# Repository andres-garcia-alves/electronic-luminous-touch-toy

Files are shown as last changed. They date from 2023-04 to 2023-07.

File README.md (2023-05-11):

# Luminous Touch Toy

Luminous Touch Toy made with NE555 IC and a piezo-electric sensor, with auto-off functionality.

&nbsp;

This project use the following electronic components:
- 1 x Integrated circuit NE555
- 1 x Piezo-electric sensor
- 4 x Multi-color LEDs
- 4 x 330 ohm resistors
- 1 x 10k ohm resistors
- 1 x 100k ohm resistor
- 1 x Transistor BC547 NPN
- 1 x Electrolitic capacitor 100uF 10v
- 1 x Switch-button
- 4 x Bateries 1.5v
- Some Empty Pen Tubes

The circuit:
- When pressing the toy surface it moves the empty pen tubes, making some presure on the piezo-electric.
- The piezo-electric generates some voltage on presure, activating the electronic circuit.
- The NE555 IC handles the 12 seconds enabled delay.

Notes:
- KiCad 6.0 schematic & PCB blueprints are also included.

&nbsp;

### Screenshots

| Diagram - Schematics | Diagram - PCB |
|---|---|
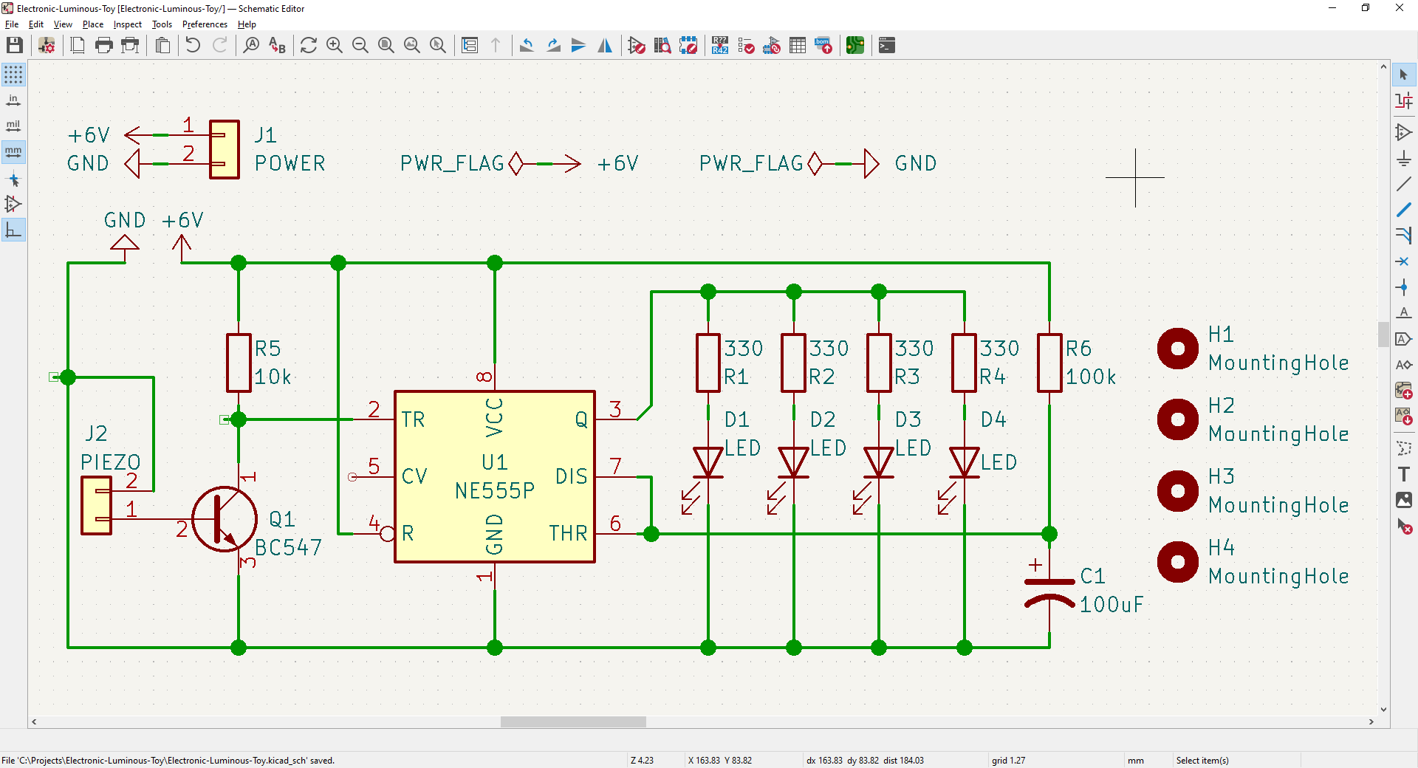
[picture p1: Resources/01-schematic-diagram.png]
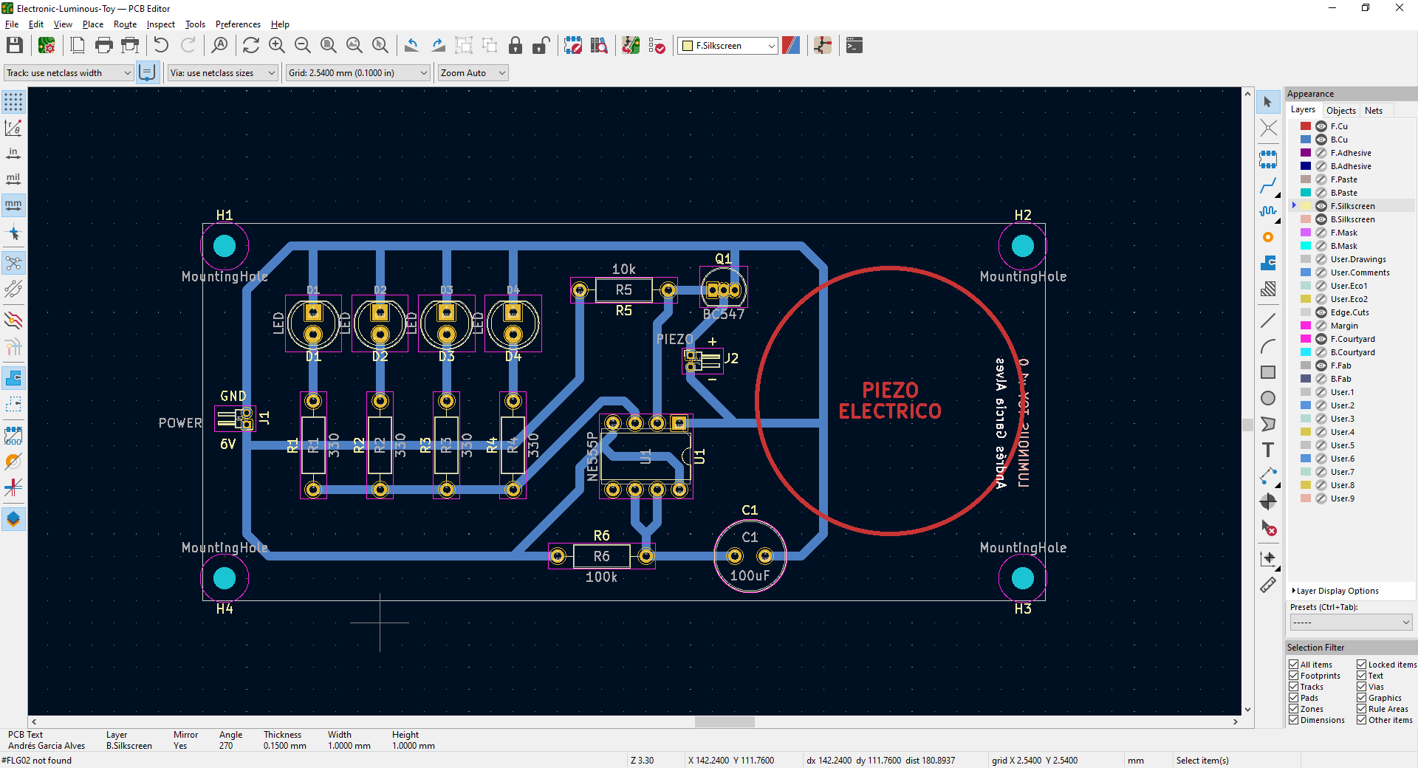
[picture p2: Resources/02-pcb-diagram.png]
|  |  |

| Diagram - PCB Render | Diagram - PCB Render |
|---|---|
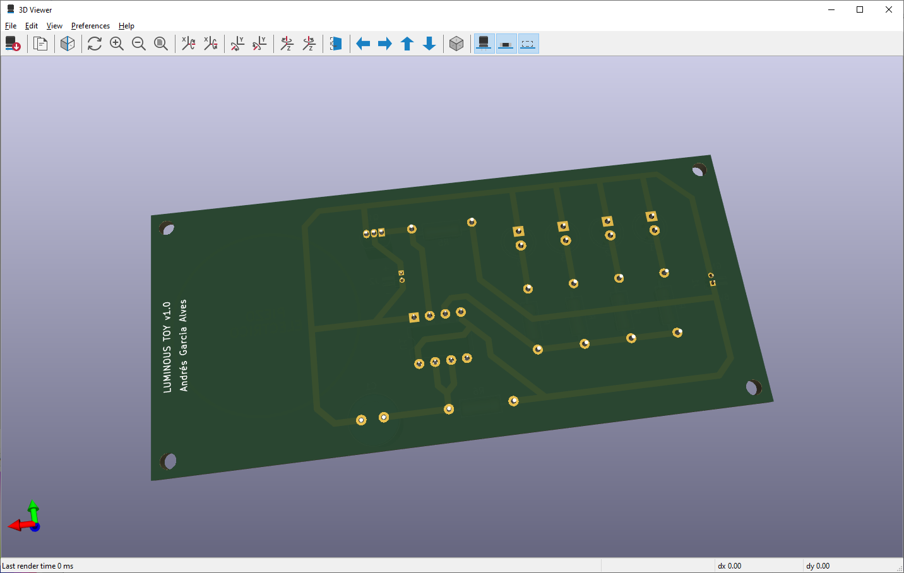
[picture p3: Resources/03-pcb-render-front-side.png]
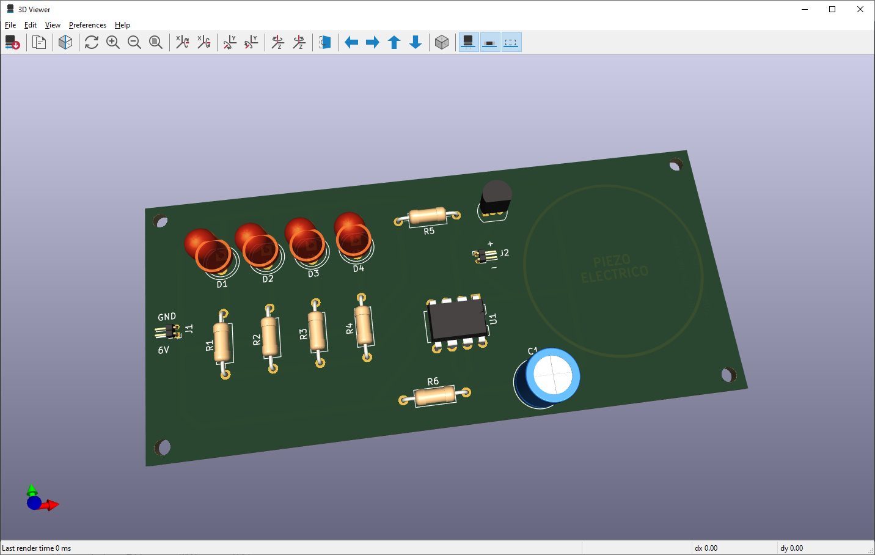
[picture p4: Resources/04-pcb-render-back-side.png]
|  |  |

| Prototype | PCB Manufacturing |
|---|---|
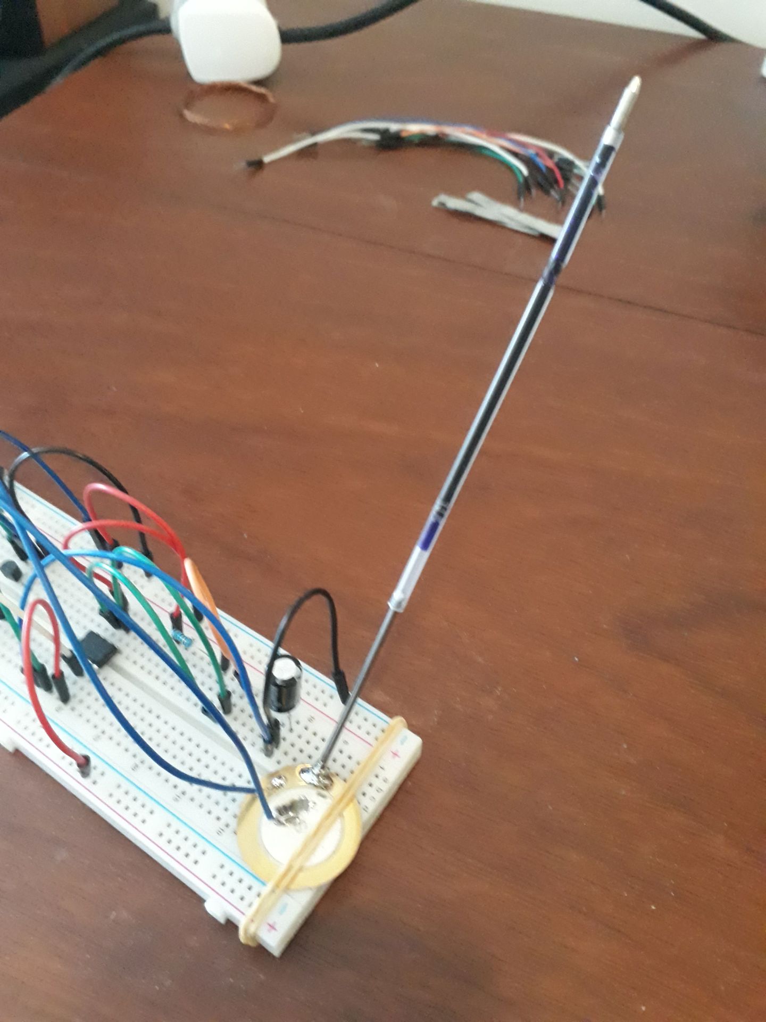
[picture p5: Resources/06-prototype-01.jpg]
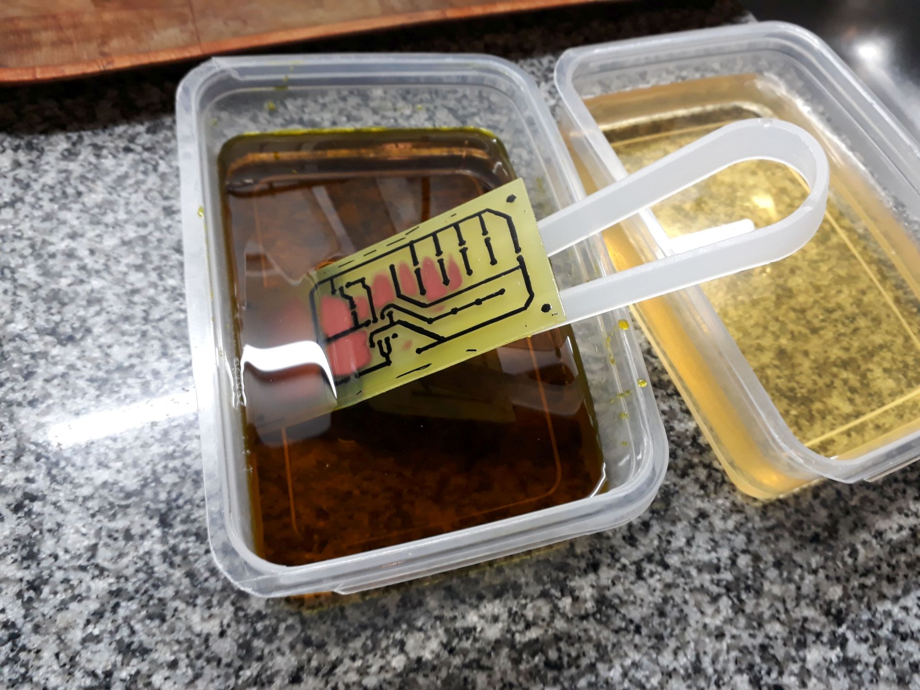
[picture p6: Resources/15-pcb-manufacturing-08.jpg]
|  |  |

| PCB Assembly | Toy Assembly |
|---|---|
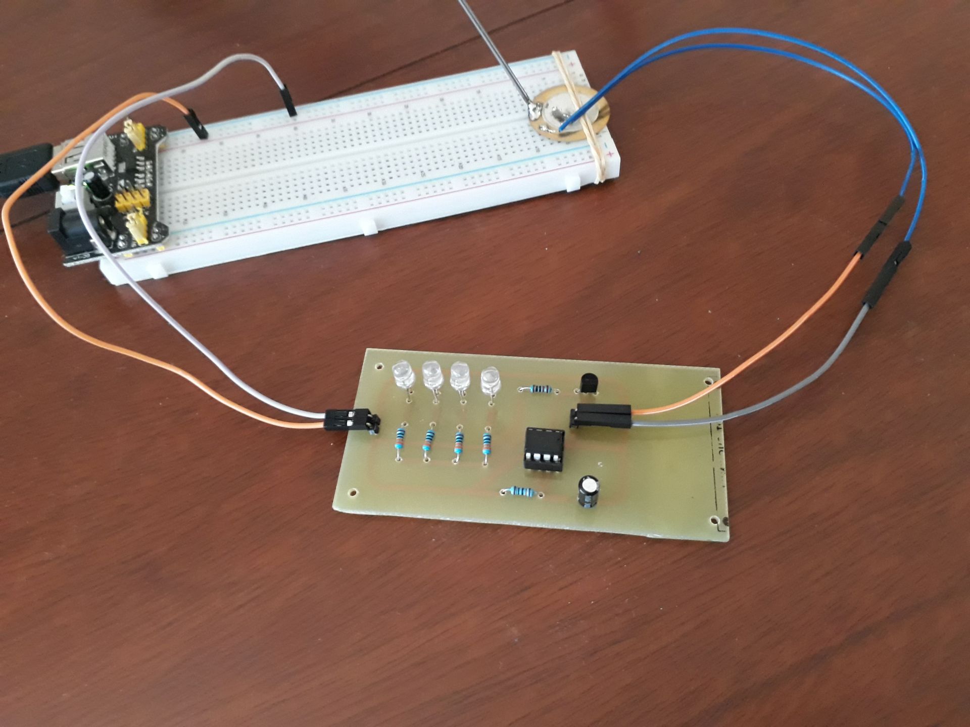
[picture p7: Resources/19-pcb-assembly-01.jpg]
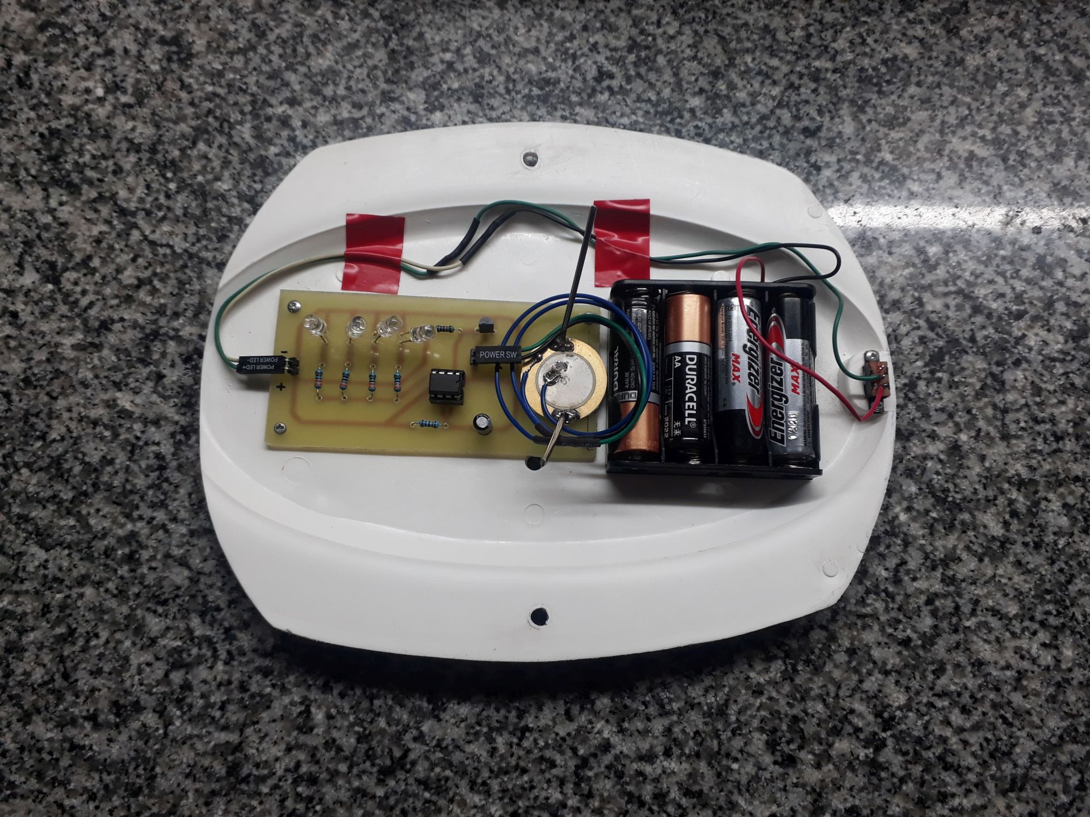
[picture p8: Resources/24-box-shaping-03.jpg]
|  |  |

| Project Final | Project Final (YouTube video) |
|---|---|
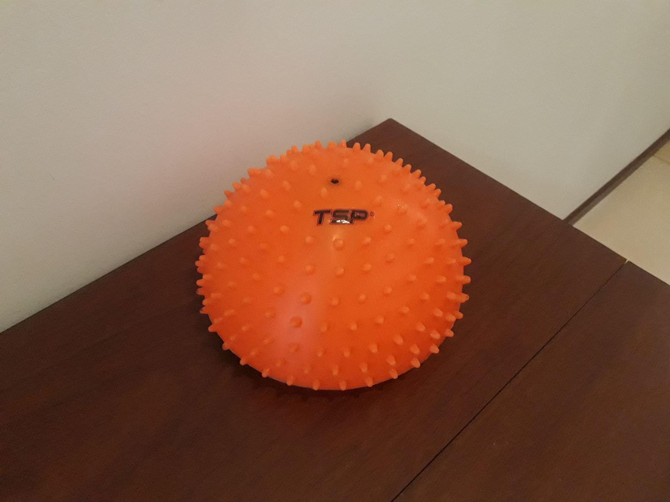
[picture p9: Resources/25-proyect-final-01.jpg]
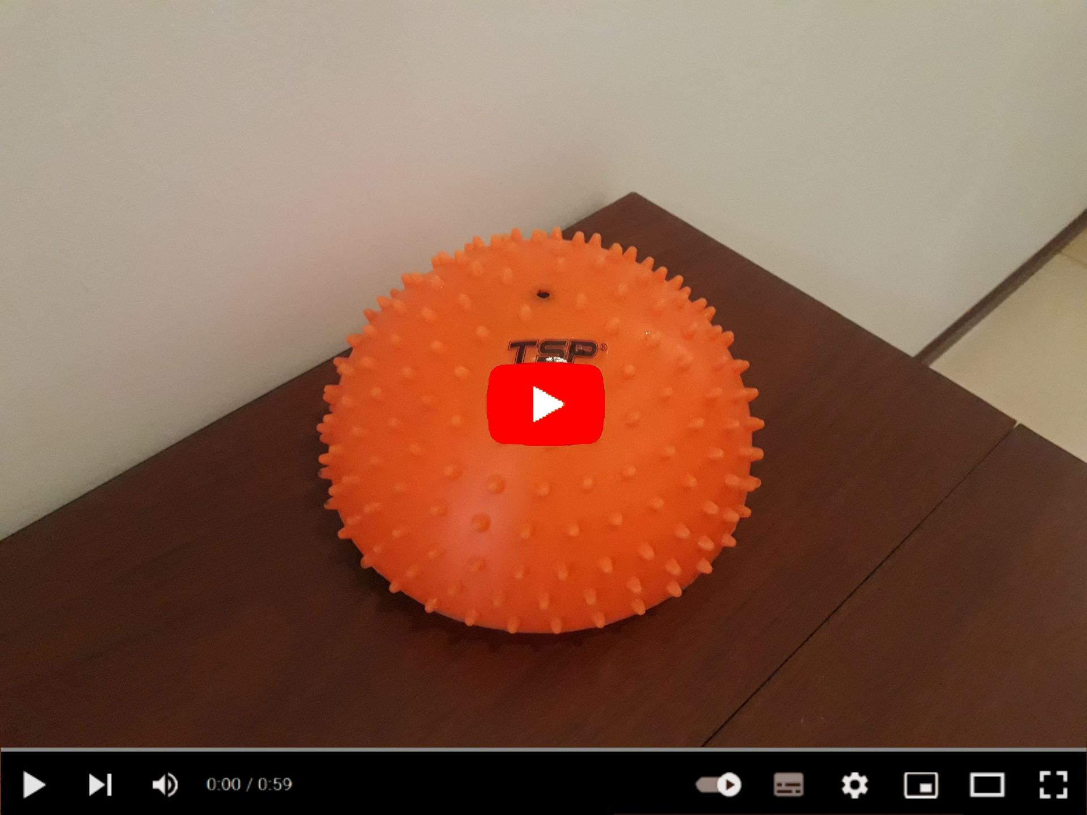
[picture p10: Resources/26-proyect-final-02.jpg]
(https://youtu.be/MLIR6YbirFM)
|  |  |

See 'Rescources' sub-folder for more pictures & videos of the project.

&nbsp;

### Version History

v1.0 (2023.04.17) - Initial release.  

&nbsp;

This source code is licensed under GPL v3.0  
Please send me your feedback about this project: andres.garcia.alves@gmail.com

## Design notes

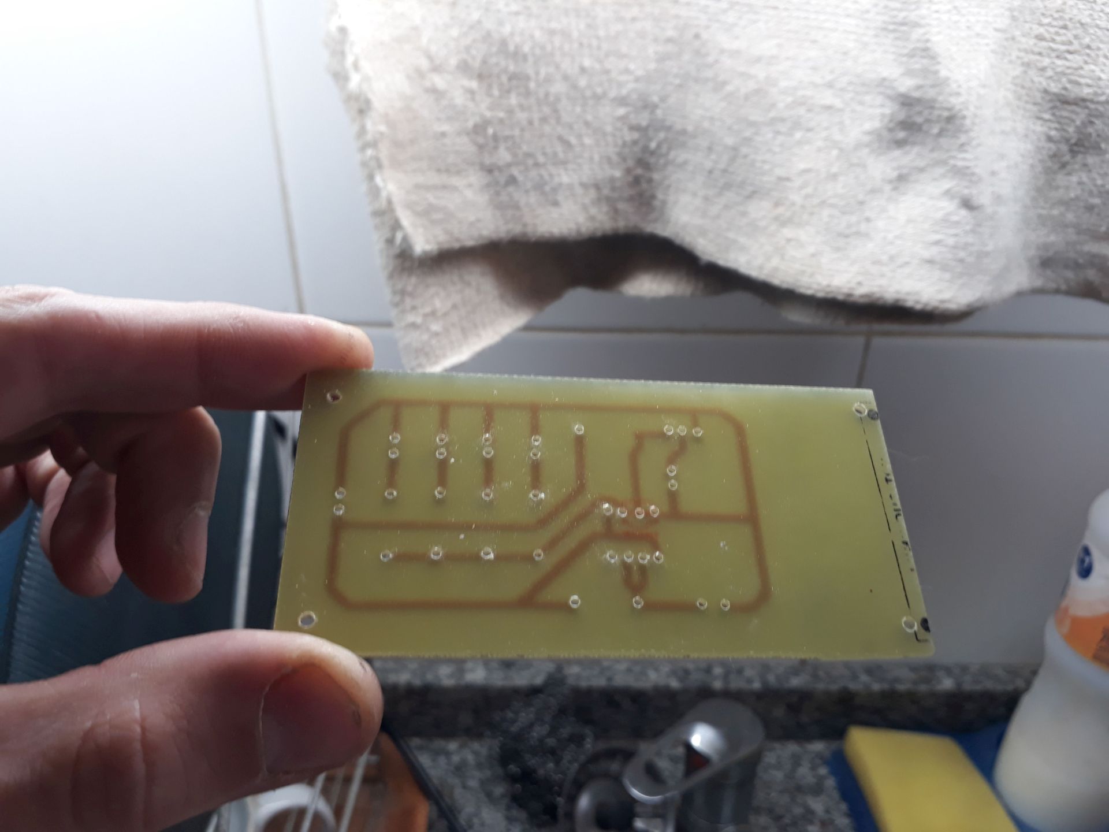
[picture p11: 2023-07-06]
Resources/18-pcb-hole-drills.jpg

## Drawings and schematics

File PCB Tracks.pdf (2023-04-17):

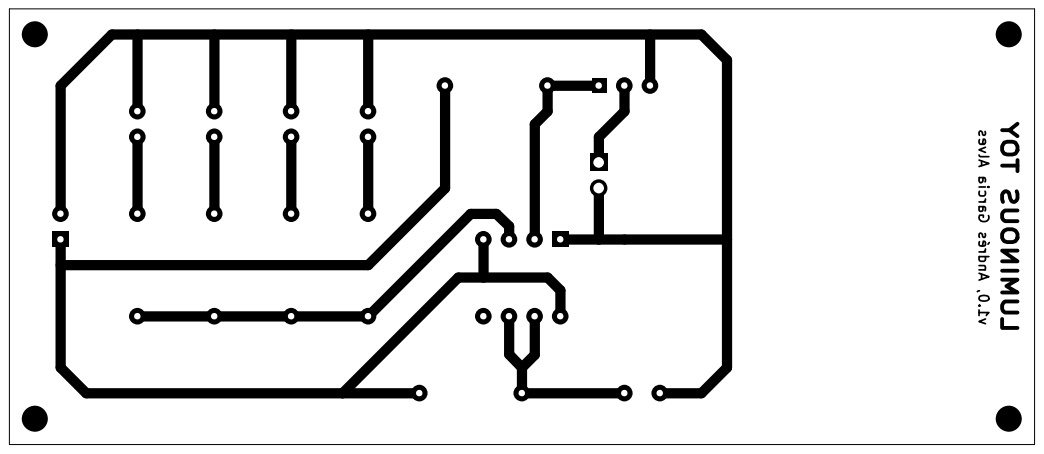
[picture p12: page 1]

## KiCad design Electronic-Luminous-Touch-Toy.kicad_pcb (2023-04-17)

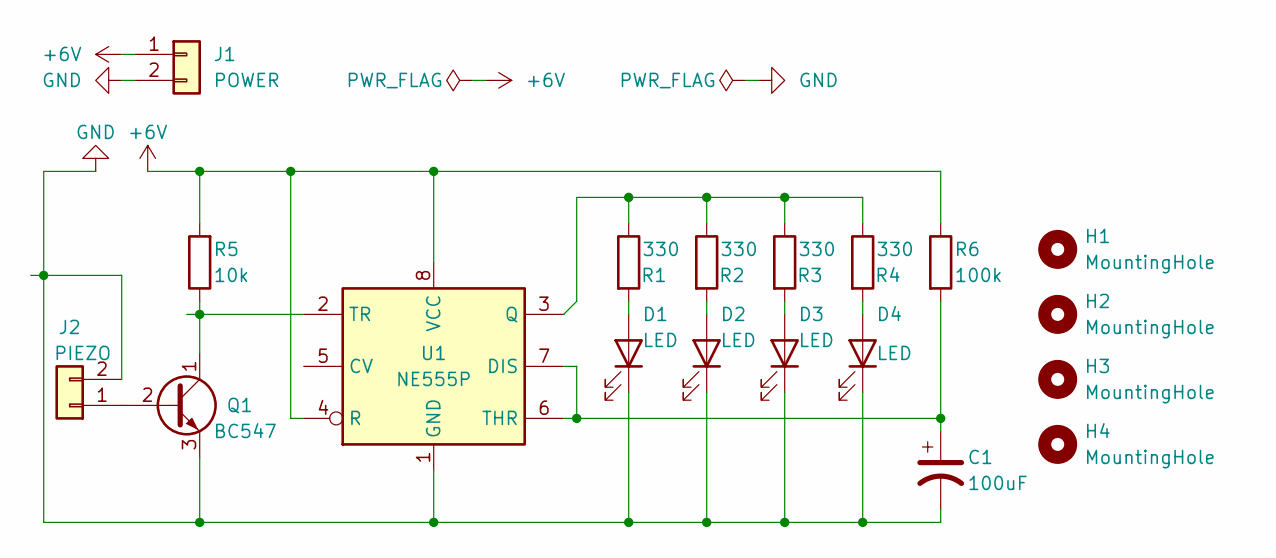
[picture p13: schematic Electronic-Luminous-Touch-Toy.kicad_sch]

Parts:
C1: 100uF; C_Radial_D8.0mm_H11.5mm_P3.50mm
D1, D2, D3, D4: LED; LED_D5.0mm
H1, H2, H3, H4: MountingHole; MountingHole_2.5mm
J1: POWER; PinHeader_1x02_P2.54mm_Horizontal
J2: PIEZO; PinHeader_1x02_P2.54mm_Horizontal
Q1: BC547; TO-92_Inline_Wide
R1, R2, R3, R4: 330; R_Axial_DIN0207_L6.3mm_D2.5mm_P10.16mm_Horizontal
R5: 10k; R_Axial_DIN0207_L6.3mm_D2.5mm_P10.16mm_Horizontal
R6: 100k; R_Axial_DIN0207_L6.3mm_D2.5mm_P10.16mm_Horizontal
U1: NE555P; DIP-8_W7.62mm

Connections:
+6V: J1.1, R5.2, R6.1, U1.4 (R), U1.8 (VCC)
GND: C1.2, D1.1 (K), D2.1 (K), D3.1 (K), D4.1 (K), J1.2, J2.2, Q1.3 (E), U1.1 (GND)
unnamed: C1.1, R6.2, U1.6 (THR), U1.7 (DIS)
unnamed: D1.2 (A), R1.2
unnamed: D2.2 (A), R2.2
unnamed: D3.2 (A), R3.2
unnamed: D4.2 (A), R4.2
unnamed: J2.1, Q1.2 (B)
unnamed: Q1.1 (C), R5.1, U1.2 (TR)
unnamed: R1.1, R2.1, R3.1, R4.1, U1.3 (Q)

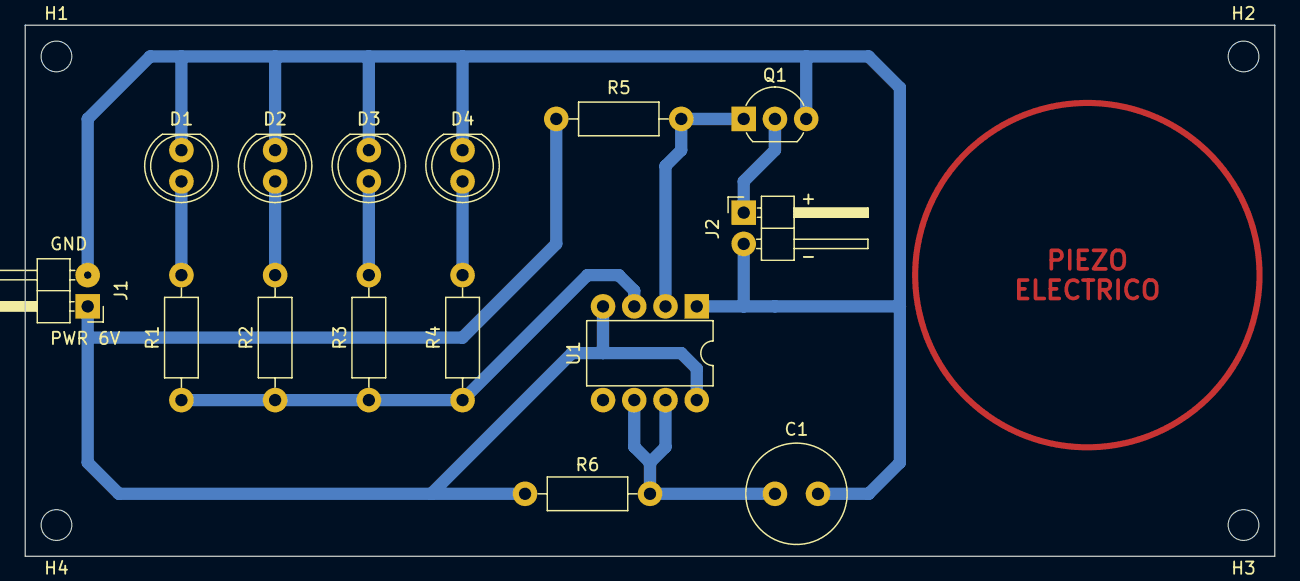
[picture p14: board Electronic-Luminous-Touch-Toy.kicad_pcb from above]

Board: 2 copper layers, 101.6 x 43.2 mm, 19 parts (0 on the bottom side), 10 nets.

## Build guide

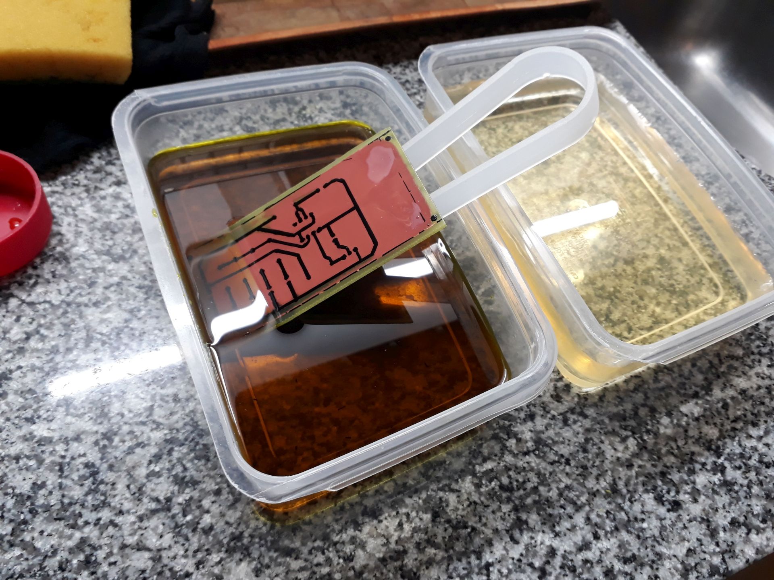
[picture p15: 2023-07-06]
Resources/14-pcb-manufacturing-07.jpg

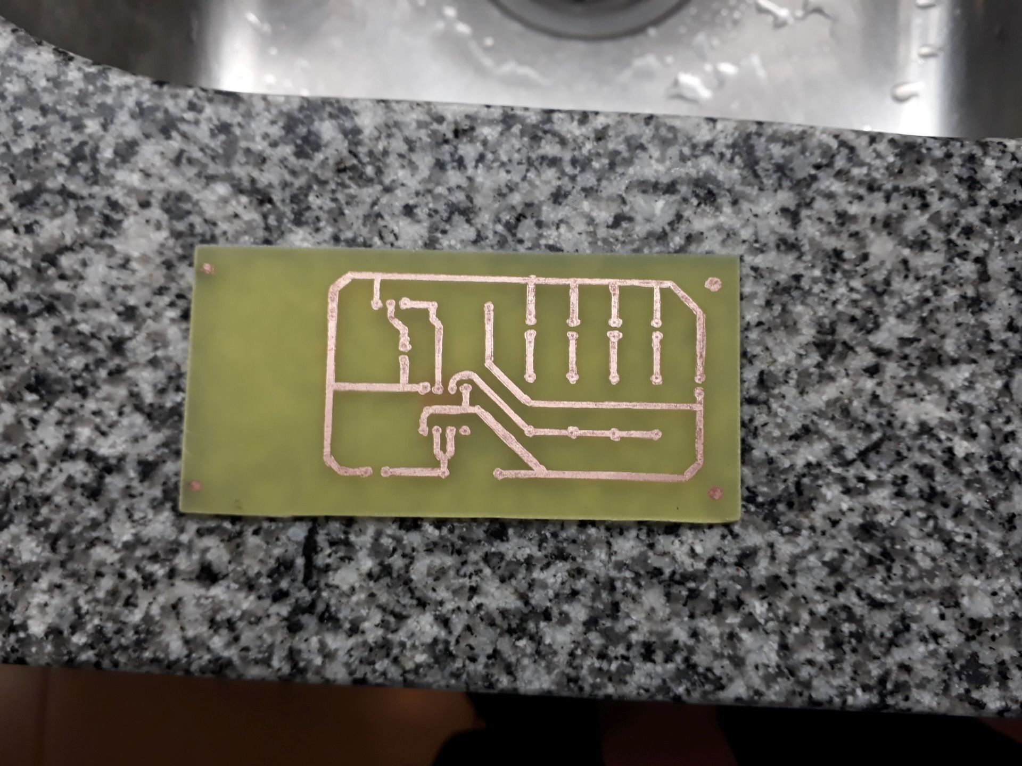
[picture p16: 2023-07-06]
Resources/17-pcb-manufacturing-10.jpg

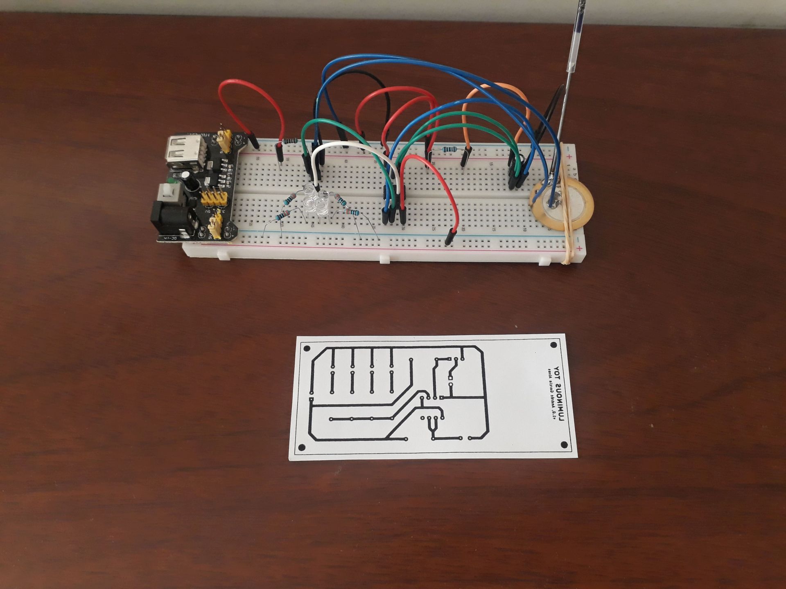
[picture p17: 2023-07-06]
Resources/08-pcb-manufacturing-01.jpg

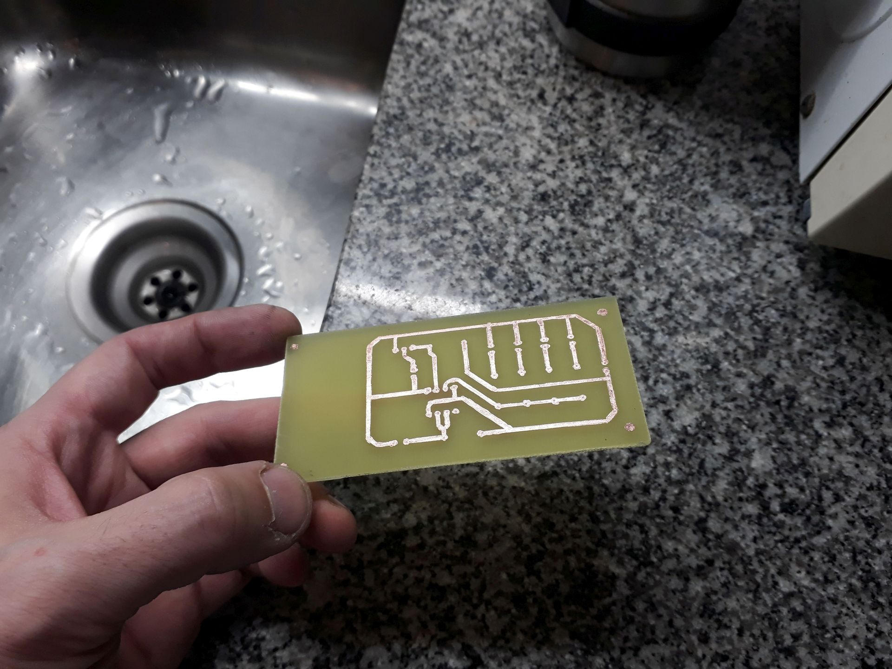
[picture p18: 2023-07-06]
Resources/16-pcb-manufacturing-09.jpg

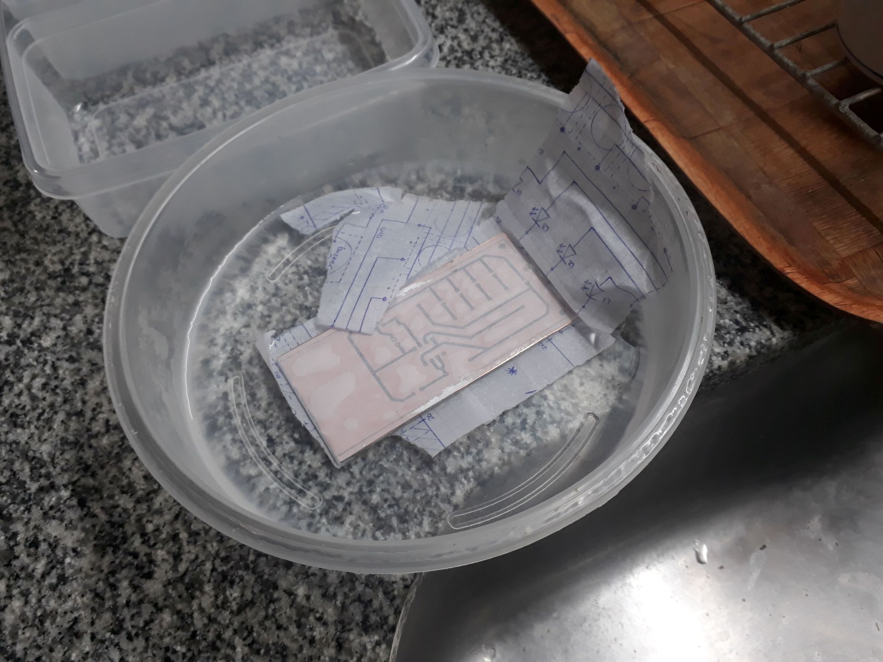
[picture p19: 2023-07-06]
Resources/09-pcb-manufacturing-02.jpg
